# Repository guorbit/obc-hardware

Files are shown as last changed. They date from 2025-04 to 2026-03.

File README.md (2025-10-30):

# STM32-based Onboard Computer

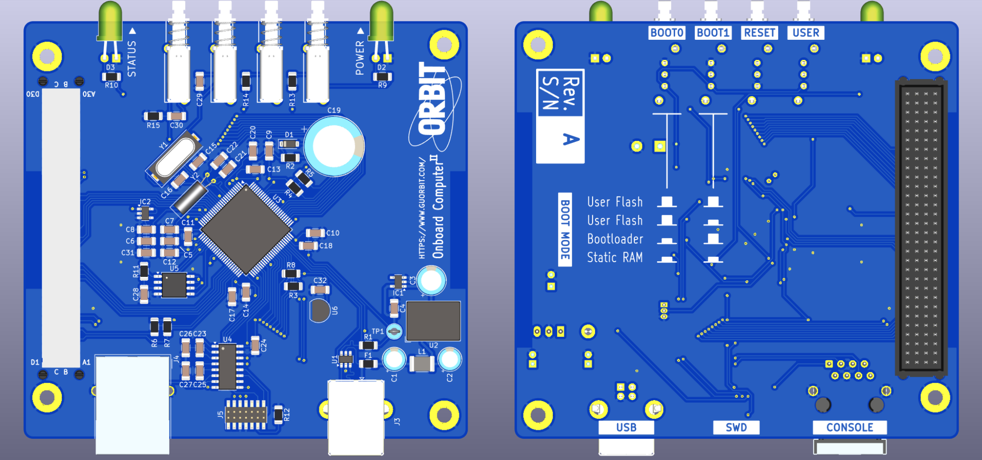
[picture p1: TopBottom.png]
rendered top and bottom view of the PCB


This repository contains the KiCad project files and fabrication outputs of GU Orbit's new generation STM32F4-based OBC board.

Revision A of this board will fly on the CloudView-2 high altitude balloon mission. This revision is an 100% COTS design with no space grade parts.

## Documentation

### User Manual

Available [HERE](https://gla.sharepoint.com/:w:/s/GUorbit/EWbB4_OCiA1IiK20_8yILmEBxFCxNbRzXe-6b-aP8d8sqQ?e=ERlZXE) (University of Glasgow login required)

### Schematic Diagram

Available [HERE](https://gla.sharepoint.com/:b:/s/GUorbit/EcqzIoVTQb1NrapEKPAgqEgBkPuZpGcCXpksztv5thLR0g?e=U3XVNj) (University of Glasgow login required)

### Mechanical Drawing

Available [HERE](https://gla.sharepoint.com/:b:/s/GUorbit/EUr8ayuSMrpKpmlO9UEF-kwB01D8GUk2koGHjnPf7s4Tdw?e=q49YmD) (University of Glasgow login required)

### 3D Model for CAD

Available under the [CAD](/CAD) directory in STEP and FreeCAD formats

## Next Revision TODOs

- [ ] Replace HSE, LSE crystals with TCXO for precision
- [ ] Use another LTC4411 to protect the SWD port

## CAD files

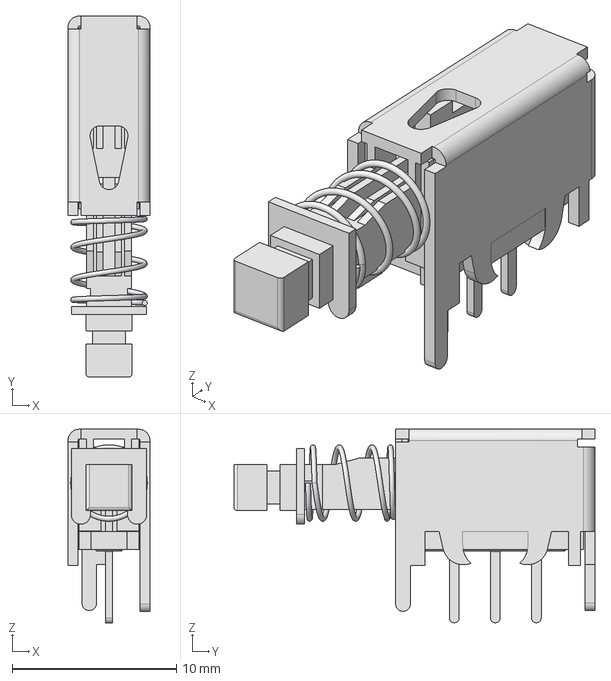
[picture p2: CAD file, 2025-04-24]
LC1258EENP/LC1258EENP.stp
5.00 x 22.0 x 11.8 mm

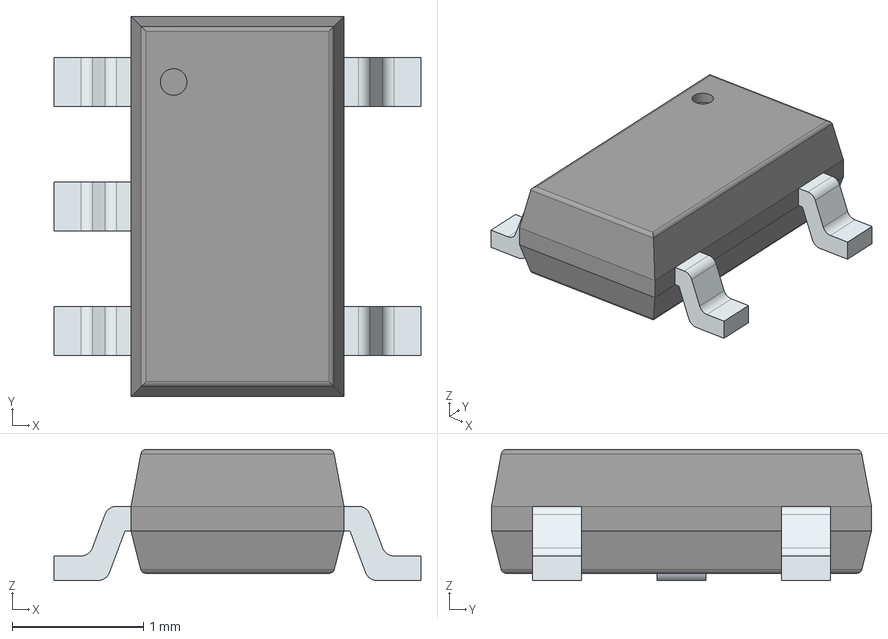
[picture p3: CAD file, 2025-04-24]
LTC4411/LTC4411ES5#TRMPBF.stp
2.80 x 2.90 x 1.00 mm
PinsArrayL
PinsArrayR

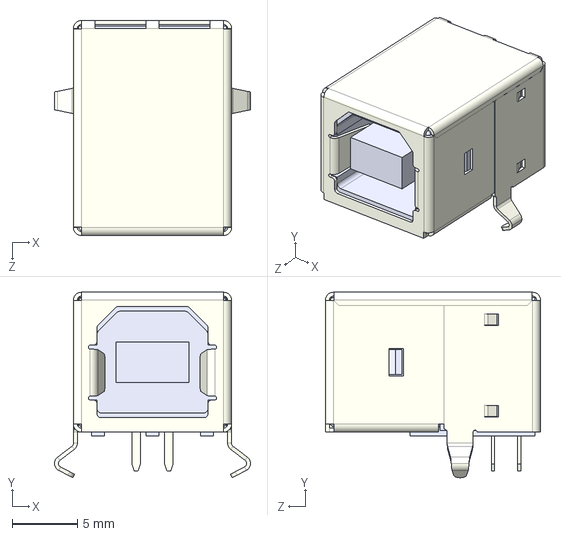
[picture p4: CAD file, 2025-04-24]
UJ2-BH-W1-TH/UJ2-BH-W1-TH.stp
15.0 x 14.2 x 16.5 mm

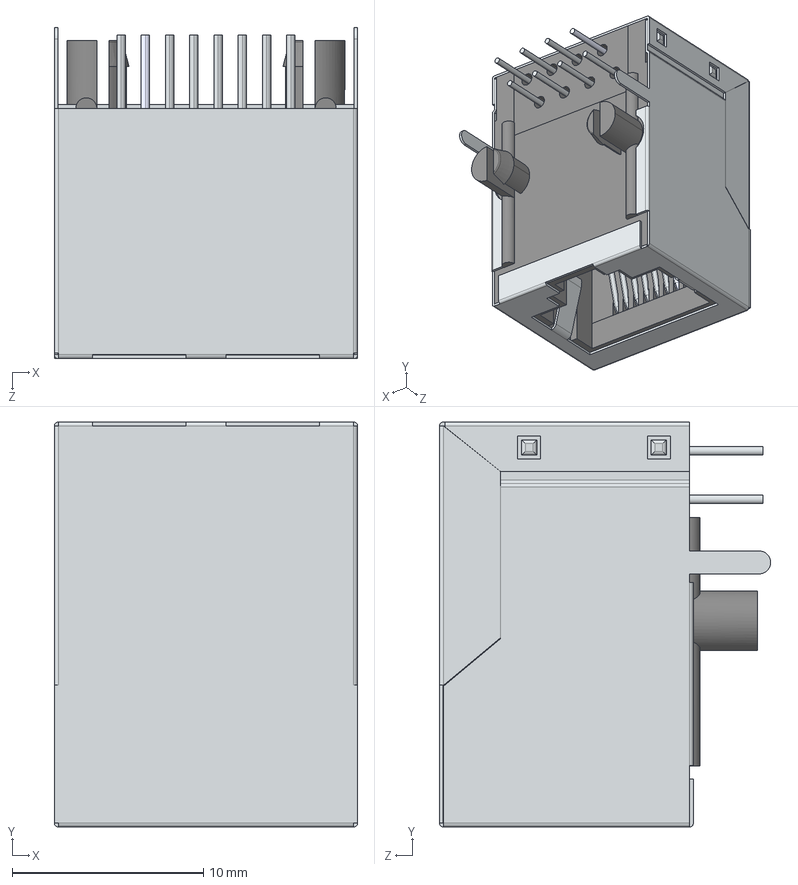
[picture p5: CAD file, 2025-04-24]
615008142621/615008142621.stp
15.9 x 21.2 x 17.3 mm
Pin1
Pin2
Pin6
Pin4
Pin3
Pin5
Pin7
Pin8
Housing
Housing2
Shielding

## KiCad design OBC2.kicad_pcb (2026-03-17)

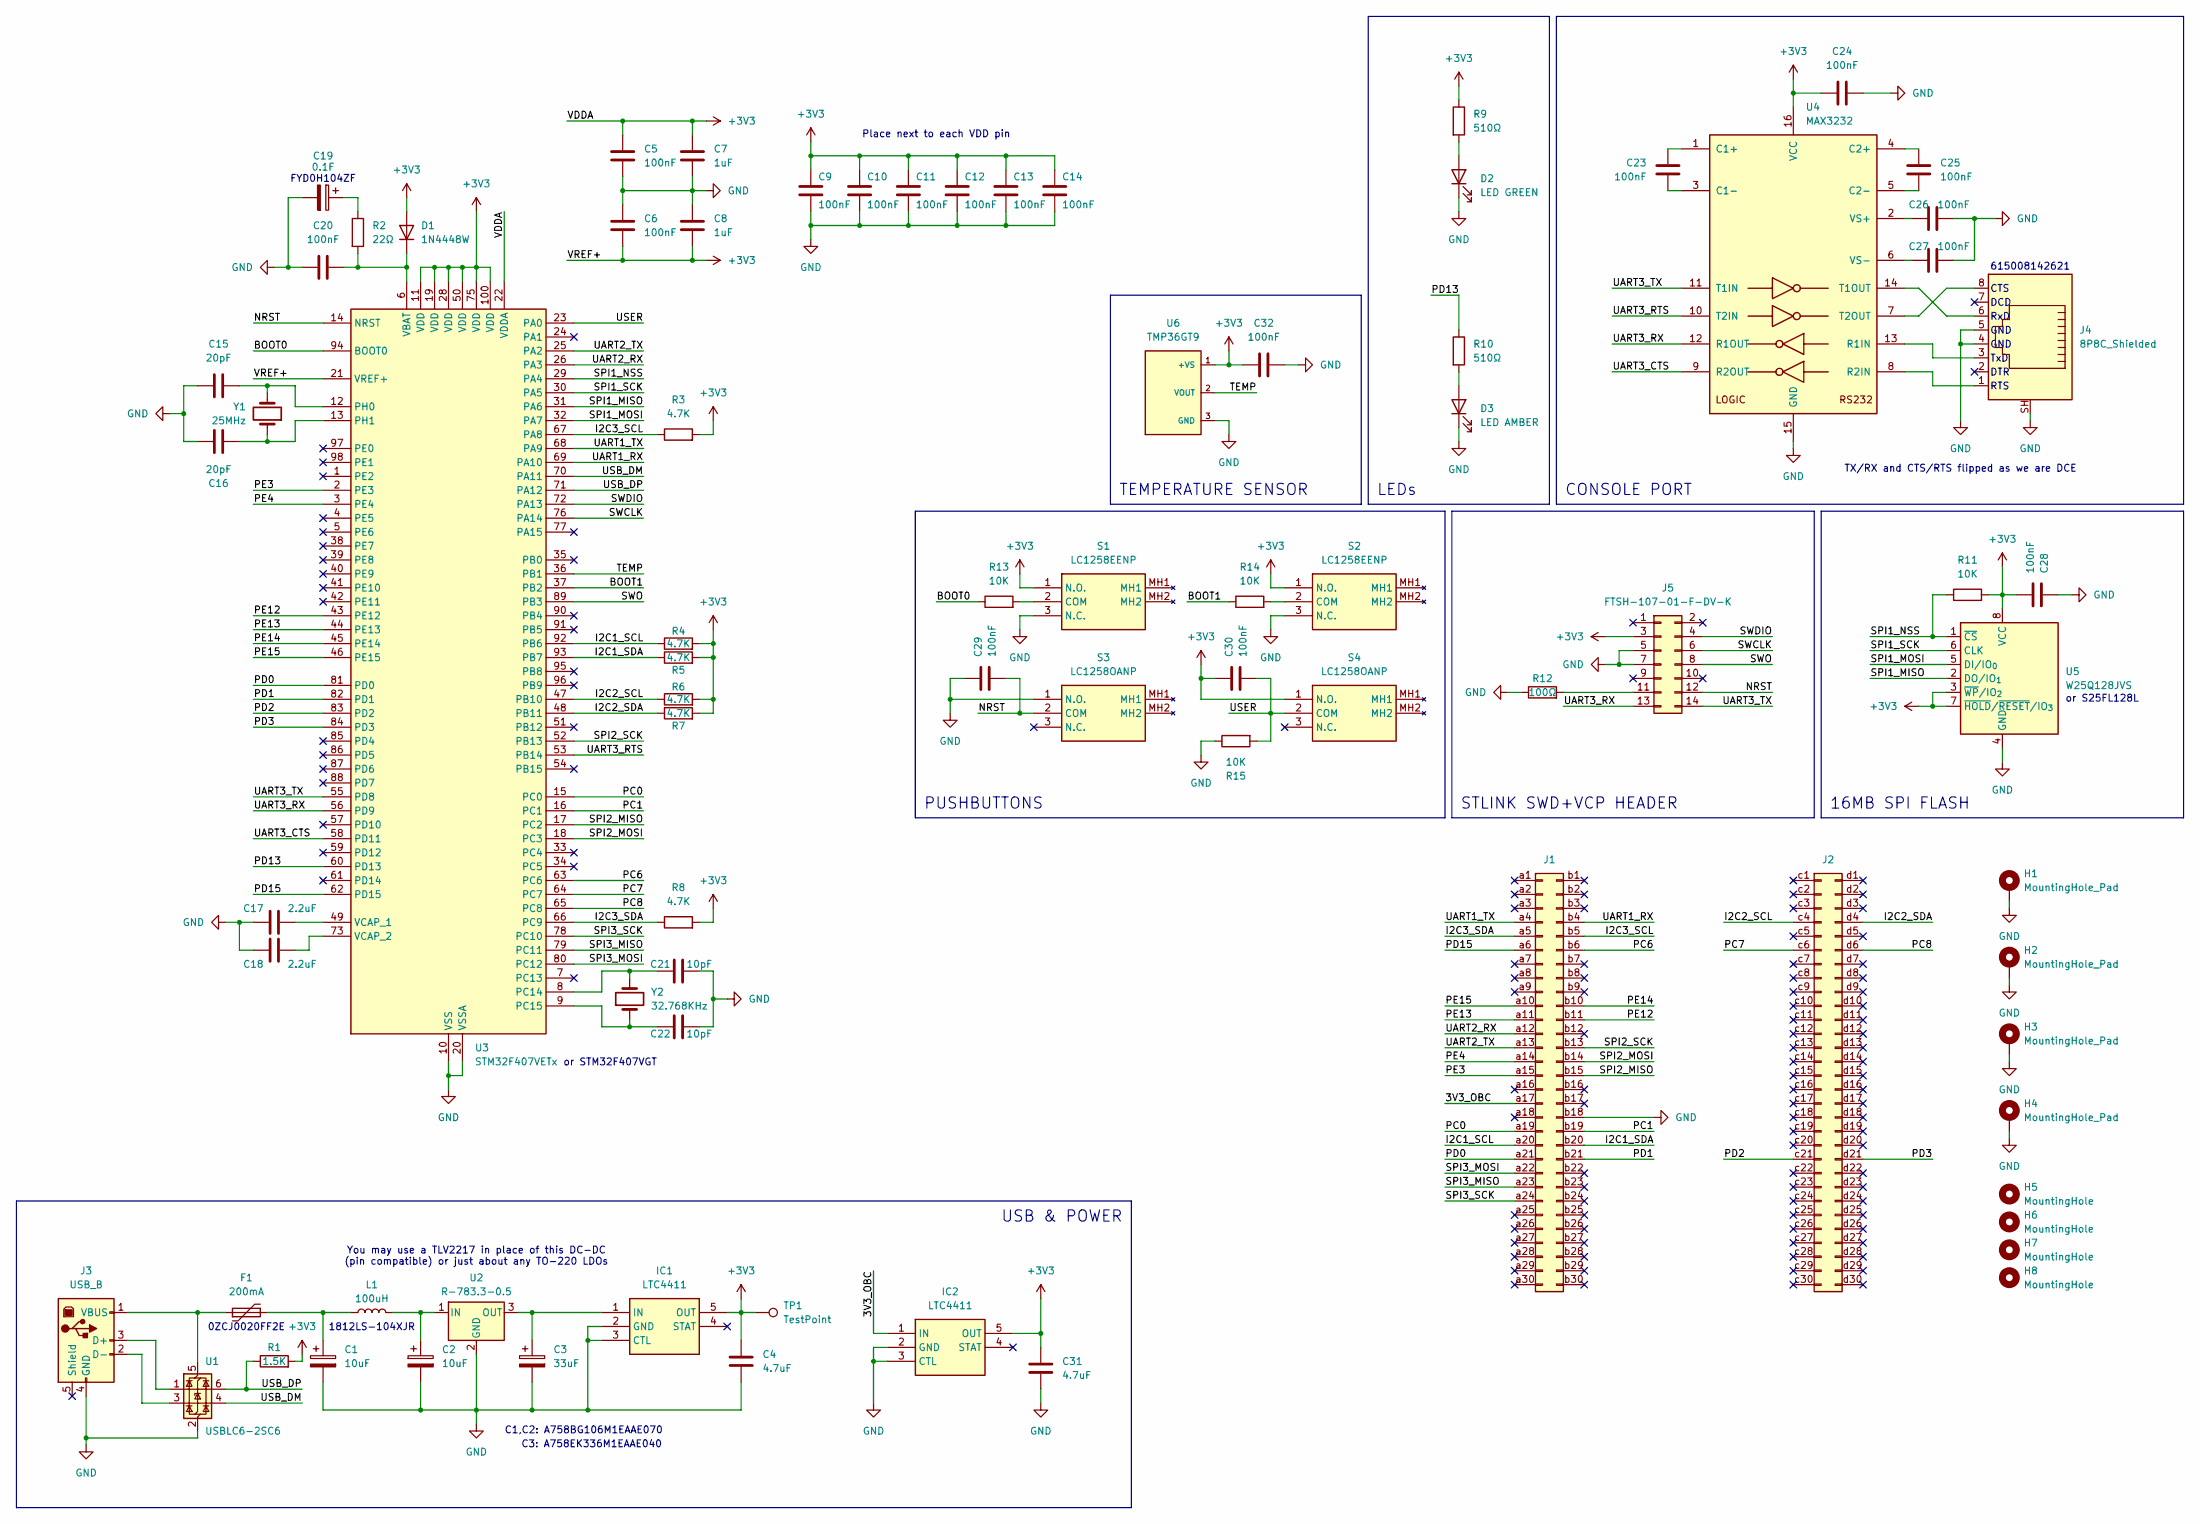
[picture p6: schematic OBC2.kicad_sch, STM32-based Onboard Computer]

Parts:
C1, C2: 10uF; CP_Radial_D5.0mm_P2.00mm
C3: 33uF; CP_Radial_D6.3mm_P2.50mm
C4, C31: 4.7uF; C_1206_3216Metric
C5, C6, C9, C10, C11, C12, C13, C14, C20, C23, C24, C25, C26, C27, C28, C29, C30, C32: 100nF; C_1206_3216Metric
C7, C8: 1uF; C_1206_3216Metric
C15, C16: 20pF; C_1206_3216Metric
C17, C18: 2.2uF; C_1206_3216Metric
C19: 0.1F; CP_Radial_D13.0mm_P5.00mm
C21, C22: 10pF; C_1206_3216Metric
D1: 1N4448W; D_SOD-123
D2: LED GREEN; LED_D5.0mm_Horizontal_O3.81mm_Z3.0mm
D3: LED AMBER; LED_D5.0mm_Horizontal_O3.81mm_Z3.0mm
F1: 200mA; Fuse_1206_3216Metric
H1, H2, H3, H4: MountingHole_Pad; MountingHole_3.2mm_M3_Pad_TopBottom
H5, H6, H7, H8: MountingHole; MountingHole_2mm
IC1, IC2: LTC4411; TSOT-23-5; Manufacturer_Part_Number LTC4411ES5#TRMPBF
J1, J2: Conn_02x30_Row_Letter_First; PinSocket_2x30_P2.00mm_Vertical
J3: USB_B; USB_B_Lumberg_2411_02_Horizontal
J4: 8P8C_Shielded; RJ45_Wuerth_7499010001A_Horizontal
J5: FTSH-107-01-F-DV-K; PinHeader_2x07_P1.27mm_Vertical_SMD
L1: 100uH; L_1812_4532Metric
R1: 1.5K; R_1206_3216Metric
R2: 22Ω; R_1206_3216Metric
R3, R4, R5, R6, R7, R8: 4.7K; R_1206_3216Metric
R9, R10: 510Ω; R_1206_3216Metric
R11, R13, R14, R15: 10K; R_1206_3216Metric
R12: 100Ω; R_1206_3216Metric
S1, S2: LC1258EENP; Manufacturer_Part_Number LC1258EENP; Mouser Part Number 612-LC1258EENP
S3, S4: LC1258OANP; Manufacturer_Part_Number LC1258OANP; Mouser Part Number 612-LC1258OANP
TP1: TestPoint; TestPoint_Loop_D2.60mm_Drill1.6mm_Beaded
U1: USBLC6-2SC6; SOT-23-6
U2: R-783.3-0.5; Converter_DCDC_RECOM_R-78E-0.5_THT
U3: STM32F407VETx; LQFP-100_14x14mm_P0.5mm
U4: MAX3232; SOIC-16_3.9x9.9mm_P1.27mm
U5: W25Q128JVS; SOIC-8_5.3x5.3mm_P1.27mm
U6: TMP36GT9; TO-92_Inline; PARTREV H
Y1: 25MHz; Crystal_SMD_HC49-SD
Y2: 32.768KHz; Crystal_C38-LF_D3.0mm_L8.0mm_Horizontal

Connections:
+3V3: C4.2, C5.2, C6.1, C7.2, C8.1, C9.2, C10.2, C11.2, C12.2, C13.2, C14.2, C24.1, C28.1, C30.1, C31.2, C32.1, D1.2 (A), IC1.5 (OUT), IC2.5 (OUT), J5.3, R1.2, R3.2, R4.2, R5.2, R6.2, R7.2, R8.2, R9.1, R11.2, S1.1 (N.O.), S2.1 (N.O.), S4.1 (N.O.), TP1.1, U3.11 (VDD), U3.19 (VDD), U3.21 (VREF+), U3.22 (VDDA), U3.28 (VDD), U3.50 (VDD), U3.75 (VDD), U3.100 (VDD), U4.16 (VCC), U5.3 (~WP/IO_{2}), U5.7 (~HOLD/~RESET/IO_{3}), U5.8 (VCC), U6.1 (+VS)
/3V3_OBC: IC2.1 (IN), J1.a17
/BOOT0: R13.1, U3.94 (BOOT0)
/BOOT1: R14.1, U3.37 (PB2)
/I2C1_SCL: J1.a20, R4.1, U3.92 (PB6)
/I2C1_SDA: J1.b20, R5.1, U3.93 (PB7)
/I2C2_SCL: J2.c4 (Pin_a4), R6.1, U3.47 (PB10)
/I2C2_SDA: J2.d4 (Pin_b4), R7.1, U3.48 (PB11)
/I2C3_SCL: J1.b5, R3.1, U3.67 (PA8)
/I2C3_SDA: J1.a5, R8.1, U3.66 (PC9)
/NRST: C29.2, J5.12, S3.2 (COM), U3.14 (NRST)
/PC0: J1.a19, U3.15 (PC0)
/PC1: J1.b19, U3.16 (PC1)
/PC6: J1.b6, U3.63 (PC6)
/PC7: J2.c6 (Pin_a6), U3.64 (PC7)
/PC8: J2.d6 (Pin_b6), U3.65 (PC8)
/PD0: J1.a21, U3.81 (PD0)
/PD1: J1.b21, U3.82 (PD1)
/PD2: J2.c21 (Pin_a21), U3.83 (PD2)
/PD3: J2.d21 (Pin_b21), U3.84 (PD3)
/PD13: R10.1, U3.60 (PD13)
/PD15: J1.a6, U3.62 (PD15)
/PE3: J1.a15, U3.2 (PE3)
/PE4: J1.a14, U3.3 (PE4)
/PE12: J1.b11, U3.43 (PE12)
/PE13: J1.a11, U3.44 (PE13)
/PE14: J1.b10, U3.45 (PE14)
/PE15: J1.a10, U3.46 (PE15)
/SPI1_MISO: U3.31 (PA6), U5.2 (DO/IO_{1})
/SPI1_MOSI: U3.32 (PA7), U5.5 (DI/IO_{0})
/SPI1_NSS: R11.1, U3.29 (PA4), U5.1 (~CS)
/SPI1_SCK: U3.30 (PA5), U5.6 (CLK)
/SPI2_MISO: J1.b15, U3.17 (PC2)
/SPI2_MOSI: J1.b14, U3.18 (PC3)
/SPI2_SCK: J1.b13, U3.52 (PB13)
/SPI3_MISO: J1.a23, U3.79 (PC11)
/SPI3_MOSI: J1.a22, U3.80 (PC12)
/SPI3_SCK: J1.a24, U3.78 (PC10)
/SWCLK: J5.6, U3.76 (PA14)
/SWDIO: J5.4, U3.72 (PA13)
/SWO: J5.8, U3.89 (PB3)
/TEMP: U3.36 (PB1), U6.2 (VOUT)
/UART1_RX: J1.b4, U3.69 (PA10)
/UART1_TX: J1.a4, U3.68 (PA9)
/UART2_RX: J1.a12, U3.26 (PA3)
/UART2_TX: J1.a13, U3.25 (PA2)
/UART3_CTS: U3.58 (PD11), U4.9 (R2OUT)
/UART3_RTS: U3.53 (PB14), U4.10 (T2IN)
/UART3_RX: J5.13, U3.56 (PD9), U4.12 (R1OUT)
/UART3_TX: J5.14, U3.55 (PD8), U4.11 (T1IN)
/USB_DM: U1.4 (I/O2), U3.70 (PA11)
/USB_DP: R1.1, U1.6 (I/O1), U3.71 (PA12)
/USER: C30.2, R15.2, S4.2 (COM), U3.23 (PA0)
GND: C1.2, C2.2, C3.2, C4.1, C5.1, C6.2, C7.1, C8.2, C9.1, C10.1, C11.1, C12.1, C13.1, C14.1, C15.1, C16.1, C17.1, C18.1, C19.2, C20.1, C21.2, C22.2, C24.2, C26.1, C27.1, C28.2, C29.1, C31.1, C32.2, D2.1 (K), D3.1 (K), H1.1, H2.1, H3.1, H4.1, IC1.2 (GND), IC1.3 (CTL), IC2.2 (GND), IC2.3 (CTL), J1.b18, J3.4 (GND), J4.4, J4.5, J4.SH, J5.5, J5.7, R12.1, R15.1, S1.3 (N.C.), S2.3 (N.C.), S3.1 (N.O.), U1.2 (GND), U2.2 (GND), U3.10 (VSS), U3.20 (VSSA), U3.27 (VSS), U3.74 (VSS), U3.99 (VSS), U4.15 (GND), U5.4 (GND), U6.3 (GND)
unnamed: C1.1, F1.2, L1.1
unnamed: C19.1, R2.1
unnamed: C20.2, D1.1 (K), R2.2, U3.6 (VBAT)
unnamed: D2.2 (A), R9.2
unnamed: D3.2 (A), R10.2
unnamed: C3.1, IC1.1 (IN), U2.3 (OUT)
unnamed: J3.3 (D+), U1.1 (I/O1)
unnamed: J3.2 (D-), U1.3 (I/O2)
unnamed: F1.1, J3.1 (VBUS), U1.5 (VBUS)
unnamed: J5.11, R12.2
unnamed: R13.2, S1.2 (COM)
unnamed: R14.2, S2.2 (COM)
unnamed: C2.1, L1.2, U2.1 (IN)
unnamed: C21.1, U3.8 (PC14), Y2.2
unnamed: C22.1, U3.9 (PC15), Y2.1
unnamed: C15.2, U3.12 (PH0), Y1.2
unnamed: C16.2, U3.13 (PH1), Y1.1
unnamed: C17.2, U3.49 (VCAP_1)
unnamed: C18.2, U3.73 (VCAP_2)
unnamed: C23.2, U4.1 (C1+)
unnamed: C23.1, U4.3 (C1-)
unnamed: C25.2, U4.4 (C2+)
unnamed: C25.1, U4.5 (C2-)
unnamed: J4.3, U4.13 (R1IN)
unnamed: J4.1, U4.8 (R2IN)
unnamed: J4.6, U4.14 (T1OUT)
unnamed: J4.8, U4.7 (T2OUT)
unnamed: C26.2, U4.2 (VS+)
unnamed: C27.2, U4.6 (VS-)

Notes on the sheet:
GND
FYD0H104ZF
or S25FL128L
CTS
RTS
TxD
C3: A758EK336M1EAAE040
Place next to each VDD pin
RxD
C1,C2: A758BG106M1EAAE070
You may use a TLV2217 in place of this DC-DC (pin compatible) or just about any TO-220 LDOs
or STM32F407VGT
615008142621
0ZCJ0020FF2E
DTR
TX/RX and CTS/RTS flipped as we are DCE
1812LS-104XJR
DCD
PUSHBUTTONS
USB & POWER
STLINK SWD+VCP HEADER
CONSOLE PORT
LEDs
TEMPERATURE SENSOR
16MB SPI FLASH

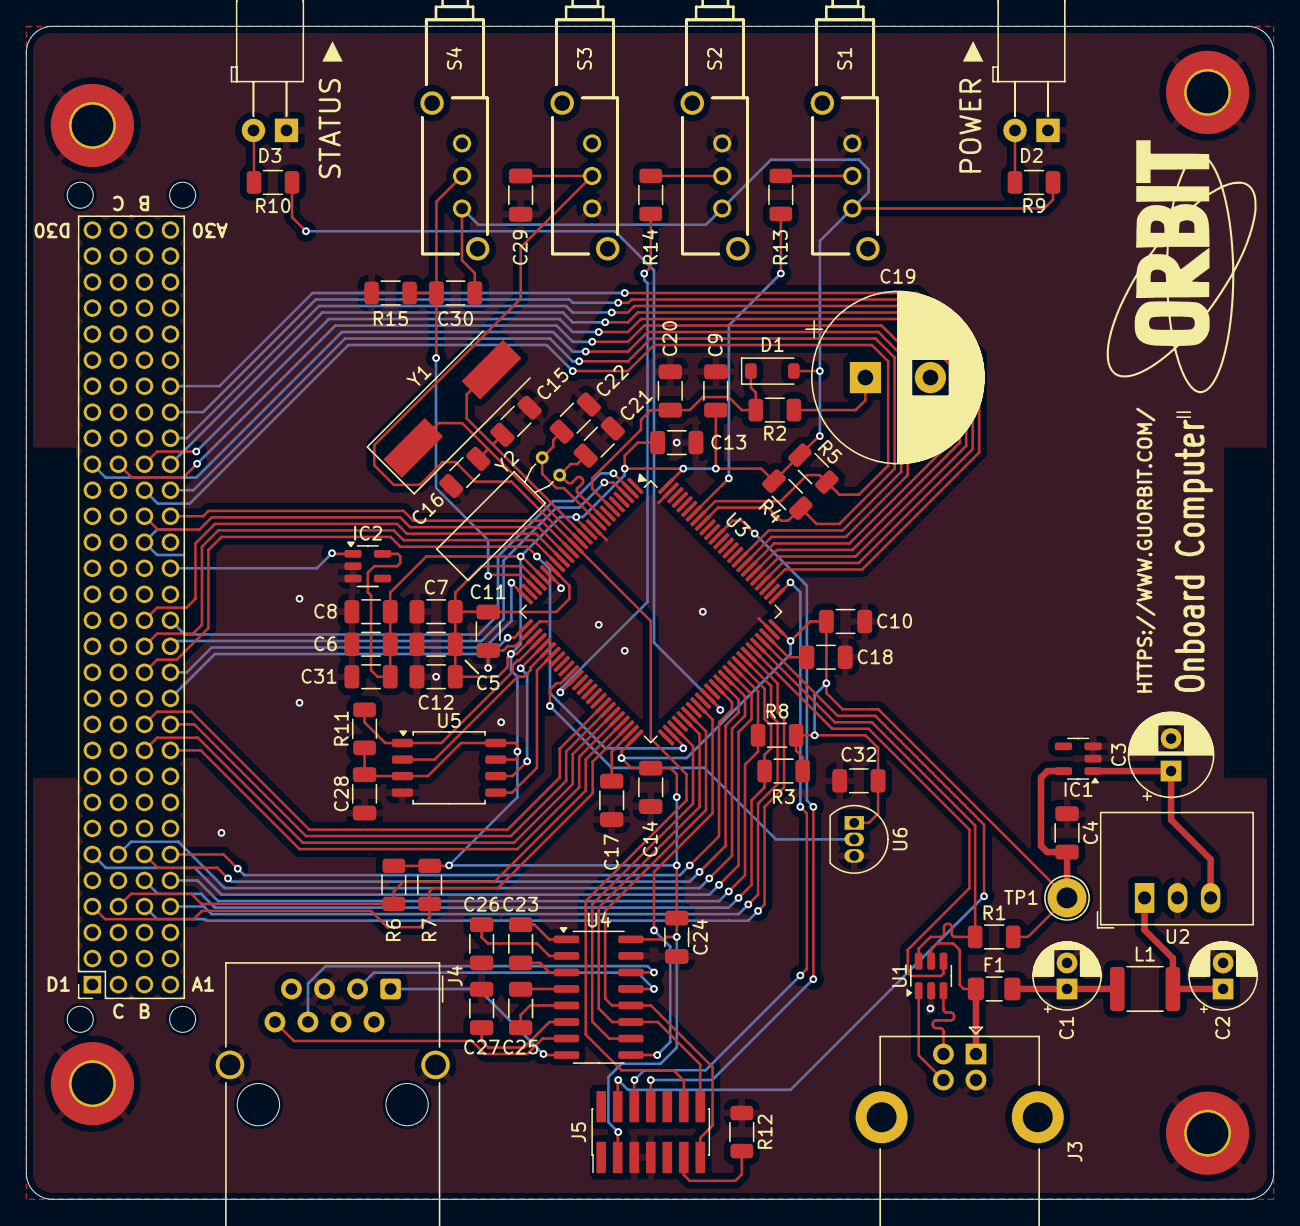
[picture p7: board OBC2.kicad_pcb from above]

Board: 2 copper layers, 95.9 x 90.2 mm, 80 parts (0 on the bottom side), 83 nets.

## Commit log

2025-04-24 Revision A
    [615008142621.stp, LC1258EENP.stp, LC1258OANP.stp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]
2025-07-08 correct through-hole sizes
    [OBC2.kicad_pcb]
2025-10-30 make the pcb bloo
    [OBC2.kicad_pcb]
2026-03-17 correct flipped i2c1 SCL SDA lines
    [OBC2.kicad_pcb, OBC2.kicad_sch]
